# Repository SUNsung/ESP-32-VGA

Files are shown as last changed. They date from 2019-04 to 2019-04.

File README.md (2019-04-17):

# ESP-32-VGA
SMD circuit implementation for connecting VGA14Bit specified in https://github.com/bitluni/ESP32Lib  D-SUB dad, calculated to insert into the monitor directly.

Input power from 5V to 9V. 

There is a power indicator, two programmable indicators, hanging on the 25 and 26 pins. 

Control of temperature stabilizer and common on thermistors is untied. VP output is responsible for the stabilizer, VN for overall temperature control.

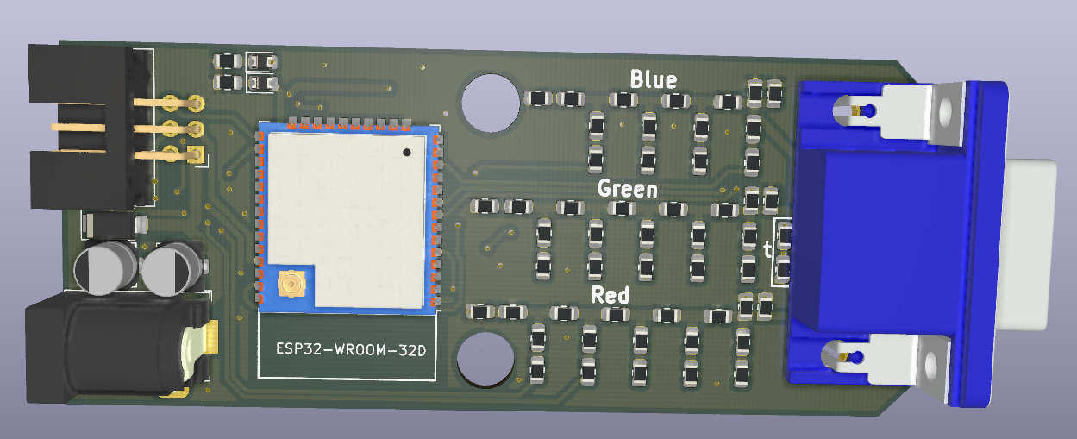
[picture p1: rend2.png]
рендер общий


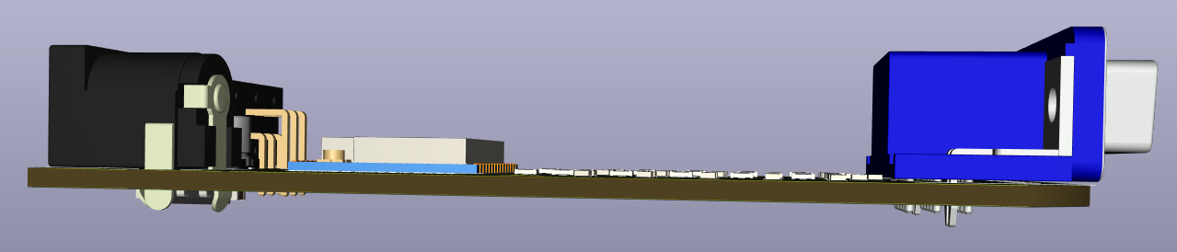
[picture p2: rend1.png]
рендер в профиль


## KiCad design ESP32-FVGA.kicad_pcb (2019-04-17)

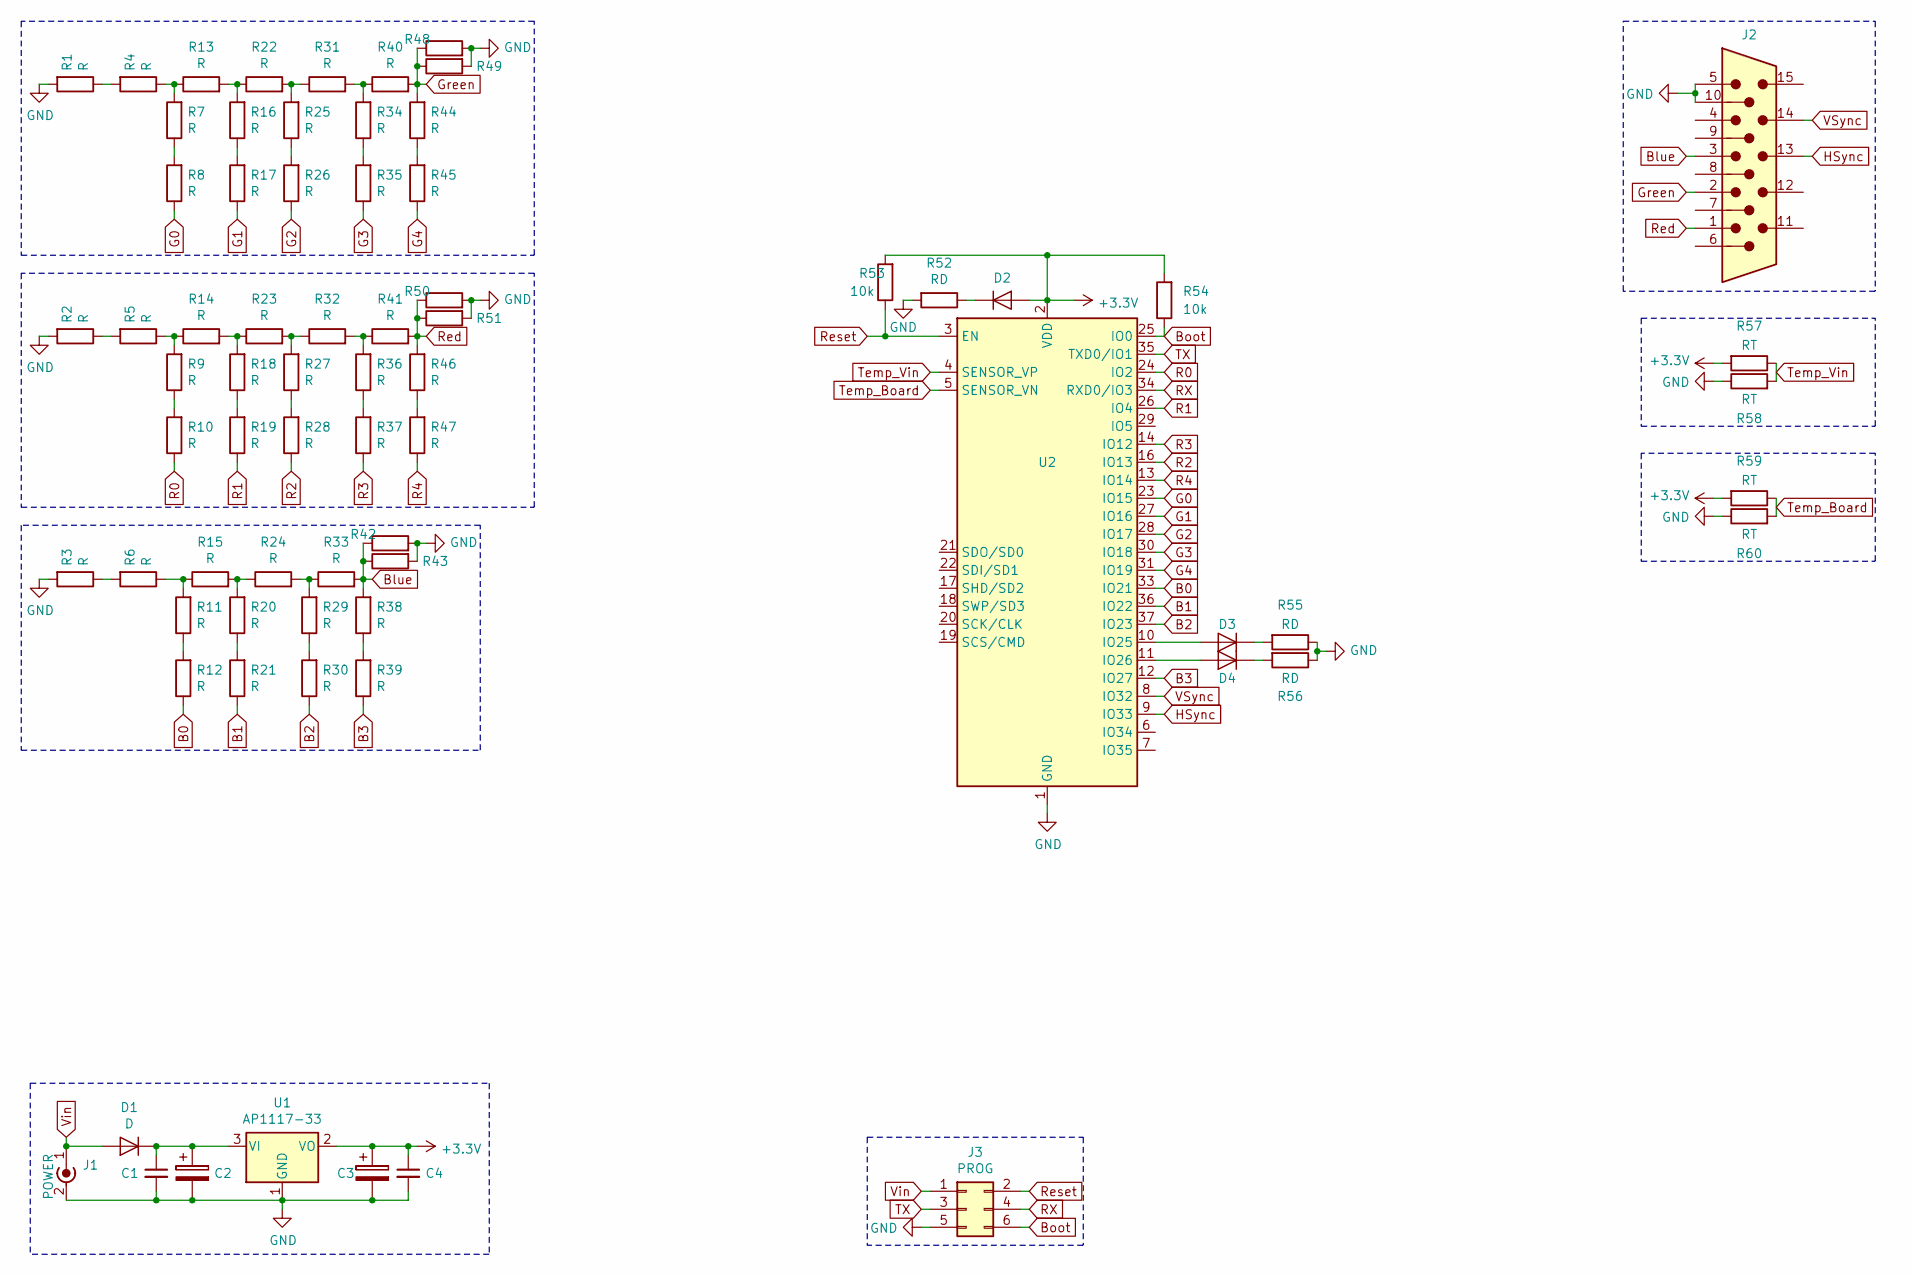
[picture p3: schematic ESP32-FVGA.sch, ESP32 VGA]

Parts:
C1, C4: C_Small; C_0805_2012Metric
C2, C3: CP; C_Elec_4x5.8
D1: D; D_SMA
D2, D3, D4: D; D_0805_2012Metric
J1: POWER; BarrelJack_Horizontal
J2: VGA; DSUB-15-HD_Male_Horizontal_P2.29x1.98mm_EdgePinOffset8.35mm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
J3: PROG; IDC-Header_2x03_P2.54mm_Horizontal
R1, R2, R3, R4, R5, R6, R7, R8, R9, R10, R11, R12, R13, R14, R15, R16, R17, R18, R19, R20, R21, R22, R23, R24, R25, R26, R27, R28, R29, R30, R31, R32, R33, R34, R35, R36, R37, R38, R39, R40, R41, R42, R43, R44, R45, R46, R47, R48, R49, R50, R51: R; R_0805_2012Metric
R52, R55, R56: RD; R_0805_2012Metric
R53, R54: 10k; R_0805_2012Metric
R57, R58, R59, R60: RT; R_0805_2012Metric
U1: AP1117-33; SOT-223-3_TabPin2
U2: ESP32-WROOM-32D; ESP32-WROOM-32U

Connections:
+3V3: C3.1, C4.1, D2.2 (A), R53.2, R54.2, R57.2, R59.2, U1.2 (VO), U2.2 (VDD)
B0: R12.1, U2.33 (IO21)
B1: R21.1, U2.36 (IO22)
B2: R30.1, U2.37 (IO23)
B3: R39.1, U2.12 (IO27)
Blue: J2.3, R33.2, R38.2, R42.1, R43.1
Boot: J3.6, R54.1, U2.25 (IO0)
G0: R8.1, U2.23 (IO15)
G1: R17.1, U2.27 (IO16)
G2: R26.1, U2.28 (IO17)
G3: R35.1, U2.30 (IO18)
G4: R45.1, U2.31 (IO19)
GND: C1.2, C2.2, C3.2, C4.2, J1.2 (Ext), J2.5, J2.10, J3.5, R1.2, R2.2, R3.2, R42.2, R43.2, R48.2, R49.2, R50.2, R51.2, R52.2, R55.1, R56.1, R58.1, R60.1, U1.1 (GND), U2.1 (GND), U2.15 (GND), U2.38 (GND), U2.39
Green: J2.2, R40.2, R44.2, R48.1, R49.1
HSync: J2.13, U2.9 (IO33)
unnamed: C1.1, C2.1, D1.1 (K), U1.3 (VI)
unnamed: D2.1 (K), R52.1
unnamed: D3.1 (K), R55.2
unnamed: D3.2 (A), U2.10 (IO25)
unnamed: D4.1 (K), R56.2
unnamed: D4.2 (A), U2.11 (IO26)
unnamed: R1.1, R4.2
unnamed: R2.1, R5.2
unnamed: R3.1, R6.2
unnamed: R7.1, R8.2
unnamed: R9.1, R10.2
unnamed: R11.1, R12.2
unnamed: R6.1, R11.2, R15.1
unnamed: R4.1, R7.2, R13.1
unnamed: R13.2, R16.2, R22.1
unnamed: R5.1, R9.2, R14.1
unnamed: R14.2, R18.2, R23.1
unnamed: R15.2, R20.2, R24.1
unnamed: R16.1, R17.2
unnamed: R18.1, R19.2
unnamed: R20.1, R21.2
unnamed: R22.2, R25.2, R31.1
unnamed: R23.2, R27.2, R32.1
unnamed: R24.2, R29.2, R33.1
unnamed: R25.1, R26.2
unnamed: R27.1, R28.2
unnamed: R29.1, R30.2
unnamed: R31.2, R34.2, R40.1
unnamed: R32.2, R36.2, R41.1
unnamed: R34.1, R35.2
unnamed: R36.1, R37.2
unnamed: R38.1, R39.2
unnamed: R44.1, R45.2
unnamed: R46.1, R47.2
R0: R10.1, U2.24 (IO2)
R1: R19.1, U2.26 (IO4)
R2: R28.1, U2.16 (IO13)
R3: R37.1, U2.14 (IO12)
R4: R47.1, U2.13 (IO14)
RX: J3.4, U2.34 (RXD0/IO3)
Red: J2.1, R41.2, R46.2, R50.1, R51.1
Reset: J3.2, R53.1, U2.3 (EN)
TX: J3.3, U2.35 (TXD0/IO1)
Temp_Board: R59.1, R60.2, U2.5 (SENSOR_VN)
Temp_Vin: R57.1, R58.2, U2.4 (SENSOR_VP)
VSync: J2.14, U2.8 (IO32)
Vin: D1.2 (A), J1.1 (In), J3.1

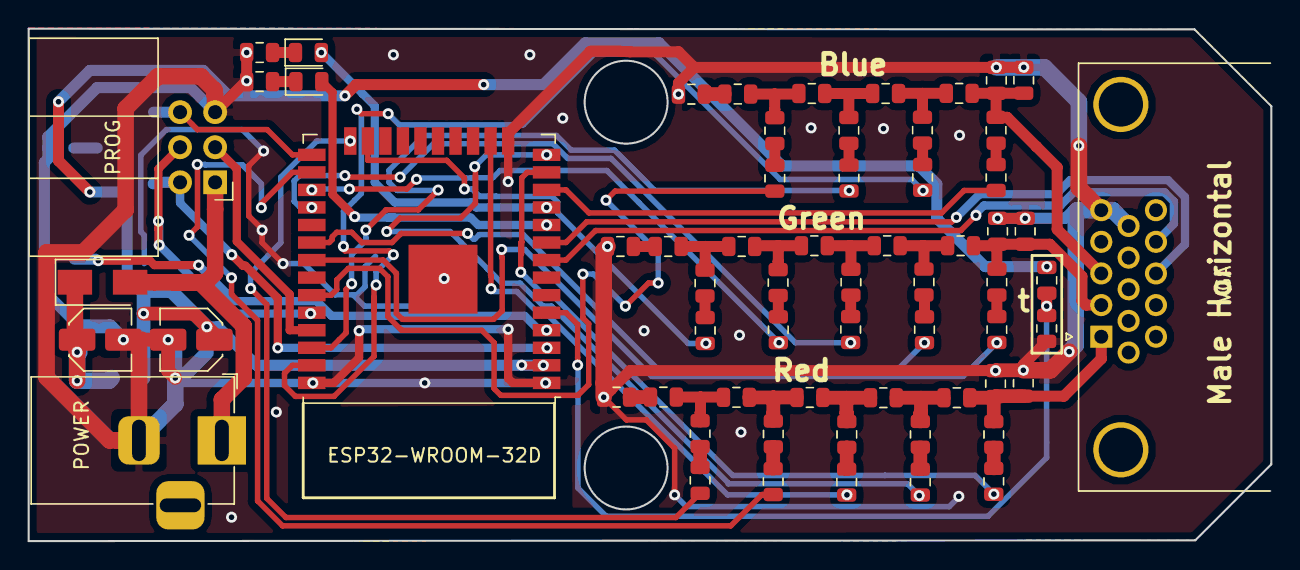
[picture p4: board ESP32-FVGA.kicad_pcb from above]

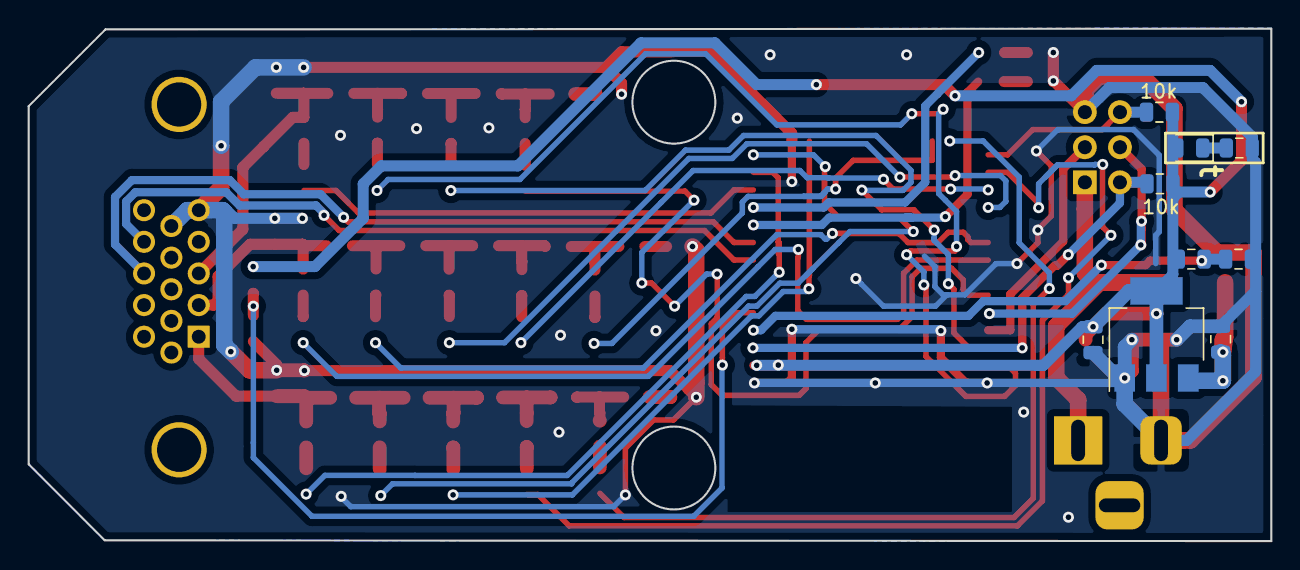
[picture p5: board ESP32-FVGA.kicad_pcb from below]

Board: 2 copper layers, 90.0 x 37.1 mm, 73 parts (9 on the bottom side), 62 nets.
